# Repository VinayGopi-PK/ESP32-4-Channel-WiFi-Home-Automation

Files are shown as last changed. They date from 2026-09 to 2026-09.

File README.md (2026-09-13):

# ESP32 4-Channel Wi-Fi Home Automation

An **ESP32-based 4-channel Wi-Fi Home Automation Controller** designed for wireless control of electrical loads using four relay outputs.

The project includes a custom hardware design developed in **KiCad**, covering the schematic, PCB layout, power supply section, ESP32 programming interface, relay control circuitry, indicators, and PCB 3D visualization.

---

## Project Overview

This project is a compact **4-channel Wi-Fi Home Automation Controller** based on an ESP32 module.

The controller is designed to provide four independent relay-controlled outputs that can be operated through the ESP32's Wi-Fi connectivity.

The PCB integrates the ESP32 controller, isolated AC-to-DC power supply, 3.3 V regulation, USB programming interface, relay control circuitry, status indicators, and four relay outputs into a single custom PCB.

### Basic System Architecture

```text
                    AC INPUT
                       │
                       ▼
              ┌─────────────────┐
              │  Isolated AC-DC │
              │   Power Supply  │
              └────────┬────────┘
                       │
                       ▼
                  +5V DC Rail
                       │
             ┌─────────┴─────────┐
             │                   │
             ▼                   ▼
       3.3V Regulator       Relay Section
             │                   │
             ▼                   ▼
          ESP32 MCU        4 × Relays
             │                   │
             └─────────┬─────────┘
                       │
                 Wi-Fi Control
                       │
                       ▼
                 Home Appliances
```

---

## Main Features

* ESP32-based Wi-Fi controller
* 4 independent relay channels
* Custom PCB designed using KiCad
* Isolated AC-to-DC power supply section
* 5 V system power rail
* 3.3 V regulated supply for ESP32
* USB interface for programming and communication
* CP2102 USB-to-UART interface
* Auto-programming support
* BOOT and RESET controls
* Individual relay control circuitry
* Status indication LEDs
* Custom PCB layout
* Front and back copper routing
* 3D PCB visualization
* Manufacturing-oriented PCB design

---

## Hardware

| Component | Function |
| --- | --- |
| ESP32 | Main microcontroller and Wi-Fi connectivity |
| HLK-PM01 | Isolated AC-to-DC power supply |
| AMS1117-3.3 | 3.3 V voltage regulation |
| CP2102 | USB-to-UART programming interface |
| SANYOU SRD Relays | Switching of four output channels |
| SS14 | Power protection / rectification section |
| BOOT Button | ESP32 boot-mode control |
| RESET Button | ESP32 reset control |
| Status LEDs | Power / system / channel indication |
| Micro USB | Power/programming interface |

---

## 4-Channel Relay Control

The PCB provides **four independent relay channels** for controlling external electrical loads.

```text
                    ESP32
                      │
          ┌───────────┼───────────┐───────────┐   
          │           │           │           │
          ▼           ▼           ▼           ▼
       Channel 1   Channel 2   Channel 3   Channel 4
          │           │           │           │
          ▼           ▼           ▼           ▼
       Relay 1     Relay 2     Relay 3     Relay 4
          │           │           │           │
          ▼           ▼           ▼           ▼
       LOAD 1      LOAD 2      LOAD 3      LOAD 4
```

Each relay channel is controlled independently by the ESP32.

---

## Power Supply

The PCB incorporates an **isolated AC-to-DC power supply section** to provide the required DC power for the controller.

The power architecture includes:

* AC input
* Isolated AC-to-DC conversion
* +5 V system rail
* 3.3 V regulation
* ESP32 power supply
* Relay power supply
* Power protection components

The design separates the low-voltage control circuitry from the incoming AC section through the isolated power supply.

---

## USB Programming Interface

The PCB includes a **CP2102 USB-to-UART interface** for programming and serial communication with the ESP32.

The programming section includes:

* Micro USB connector
* CP2102 USB-to-UART bridge
* ESP32 UART connection
* Auto-programming circuitry
* BOOT control
* RESET control

This allows the ESP32 firmware to be programmed without requiring a separate external USB-to-UART module.

---

## Indicators and Controls

The design includes dedicated user-interface components for operating and monitoring the controller.

### Controls

* BOOT button
* RESET button

### Indicators

* Power/system status indication
* Relay/channel status indication

The PCB uses compact SMD LEDs for status indication while retaining convenient physical controls for programming and reset operations.

---

## PCB Design

The complete PCB was designed using **KiCad**.

The design includes:

* Complete electrical schematic
* Component selection and footprint assignment
* PCB component placement
* Signal routing
* Power routing
* Ground plane
* Relay section
* AC input section
* USB programming section
* ESP32 section
* Front and back PCB layout
* 3D PCB visualization
* Manufacturing files

---

## PCB Design Preview

### Schematic

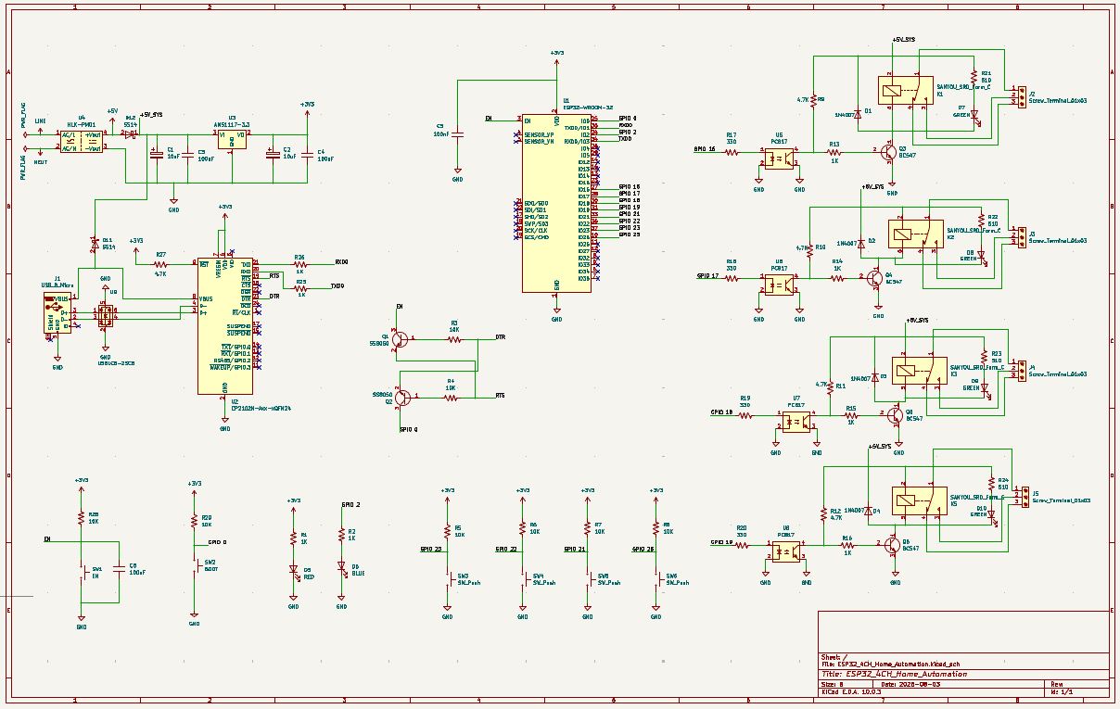
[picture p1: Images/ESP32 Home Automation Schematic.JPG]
ESP32 Home Automation Schematic


### PCB Front Layout

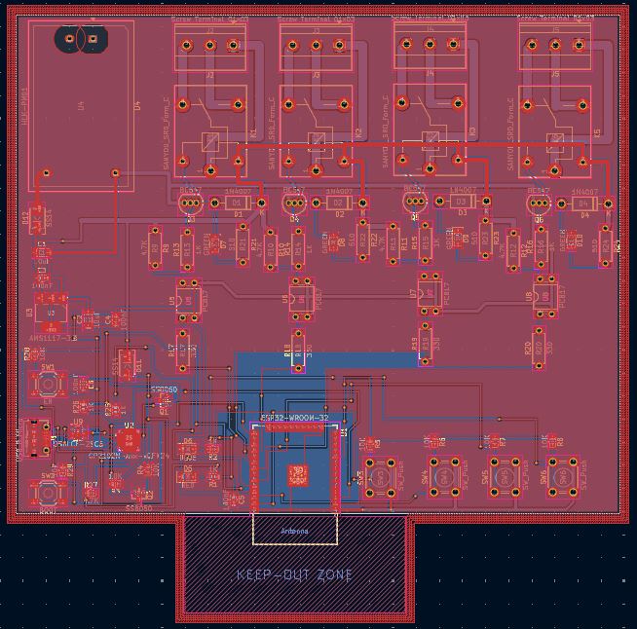
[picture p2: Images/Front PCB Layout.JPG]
ESP32 4-Channel Home Automation PCB Front Layout


### PCB Back Layout

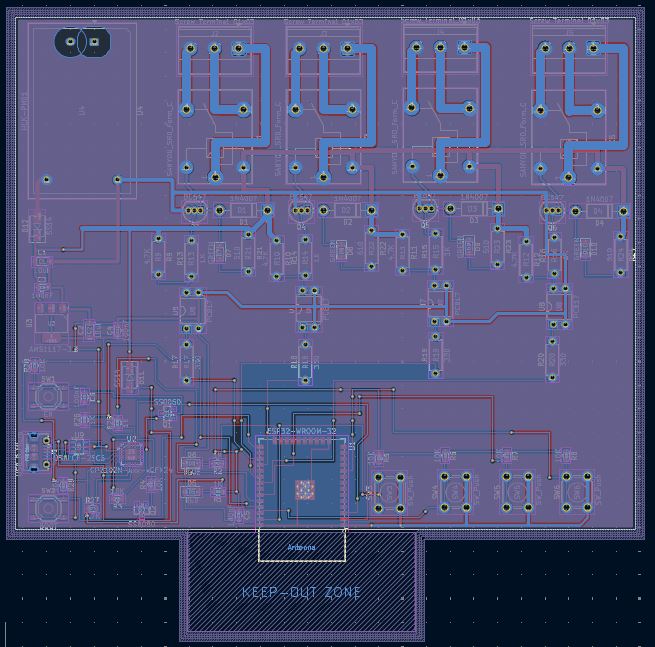
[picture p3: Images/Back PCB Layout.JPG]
ESP32 4-Channel Home Automation PCB Back Layout


### 3D View

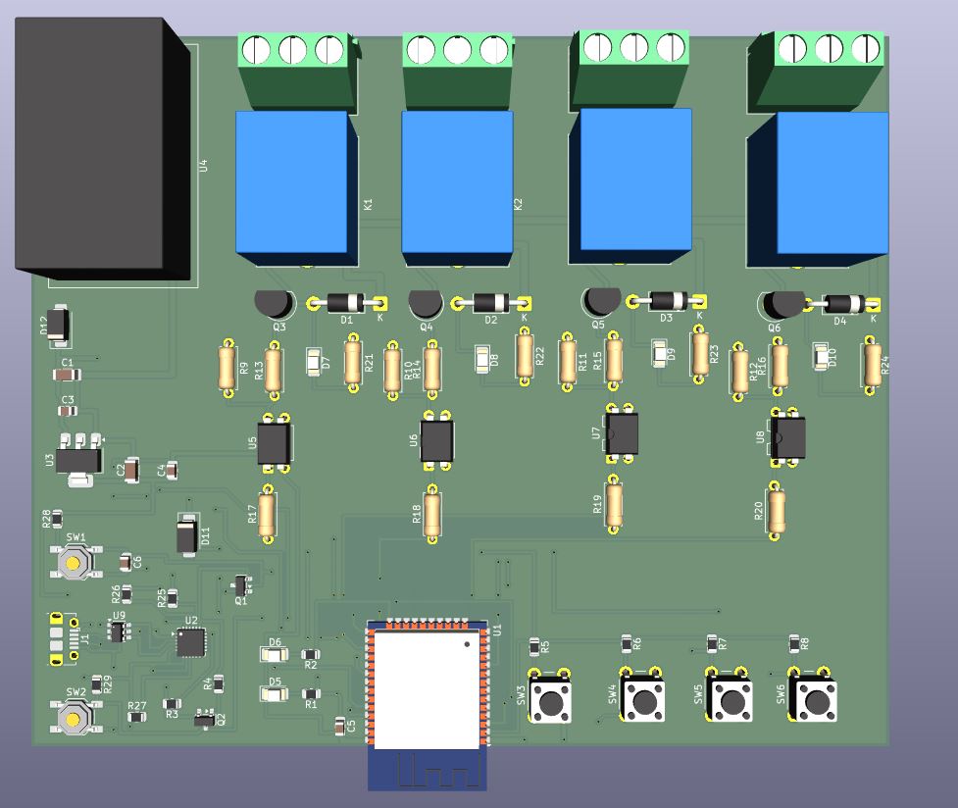
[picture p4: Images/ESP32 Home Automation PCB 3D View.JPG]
ESP32 4-Channel Home Automation PCB 3D View


---

## Design Considerations

The PCB design considers the separation between the **AC mains section and low-voltage electronics**.

Important design considerations include:

* Isolation between AC input and low-voltage circuitry
* Dedicated power distribution
* Ground-plane implementation
* Appropriate PCB clearances
* Relay switching section
* ESP32 signal routing
* USB programming interface
* Component placement
* Manufacturing requirements

> **Safety note:** This project involves mains-voltage circuitry. The PCB should only be assembled, tested, and operated by appropriately qualified personnel using suitable electrical safety practices and enclosure/isolation measures.

---

## Design Tools

* **KiCad** — Schematic and PCB design
* **ESP32** — Embedded Wi-Fi controller
* **CP2102** — USB-to-UART interface

---

## Technical Highlights

**Microcontroller:** ESP32
**Wireless Communication:** Wi-Fi
**Relay Channels:** 4
**AC-DC Power Supply:** HLK-PM01
**Logic Supply:** 3.3 V
**USB-UART:** CP2102
**Relay:** SANYOU SRD Series
**PCB Design Tool:** KiCad
**PCB Type:** Custom PCB

---

## Repository Contents

The repository contains the project design files, PCB manufacturing files, documentation, and project images.

### KiCad Project

Contains:

* KiCad schematic
* KiCad PCB layout
* KiCad project files
* Component and footprint configuration files

### Documentation

Contains project-related documentation and component information.

### Gerber Files

Contains the generated PCB manufacturing files.

### Images

Contains:

* Schematic
* PCB front layout
* PCB back layout
* PCB 3D view

---

## Project Objective

The objective of this project was to design a **compact 4-channel ESP32-based Wi-Fi Home Automation Controller** integrating wireless control, relay switching, isolated power conversion, USB programming, and custom PCB design into a single hardware platform.

The project demonstrates skills in:

* Embedded system hardware design
* ESP32-based systems
* Wi-Fi-enabled control systems
* Power supply design
* Relay control
* USB-to-UART programming
* Schematic design
* PCB layout
* Component selection
* PCB manufacturing file generation

---

## Project Type

**ESP32 Embedded System | Wi-Fi Home Automation | Relay Controller | PCB Design**

**Design Software:** KiCad
**Controller:** ESP32

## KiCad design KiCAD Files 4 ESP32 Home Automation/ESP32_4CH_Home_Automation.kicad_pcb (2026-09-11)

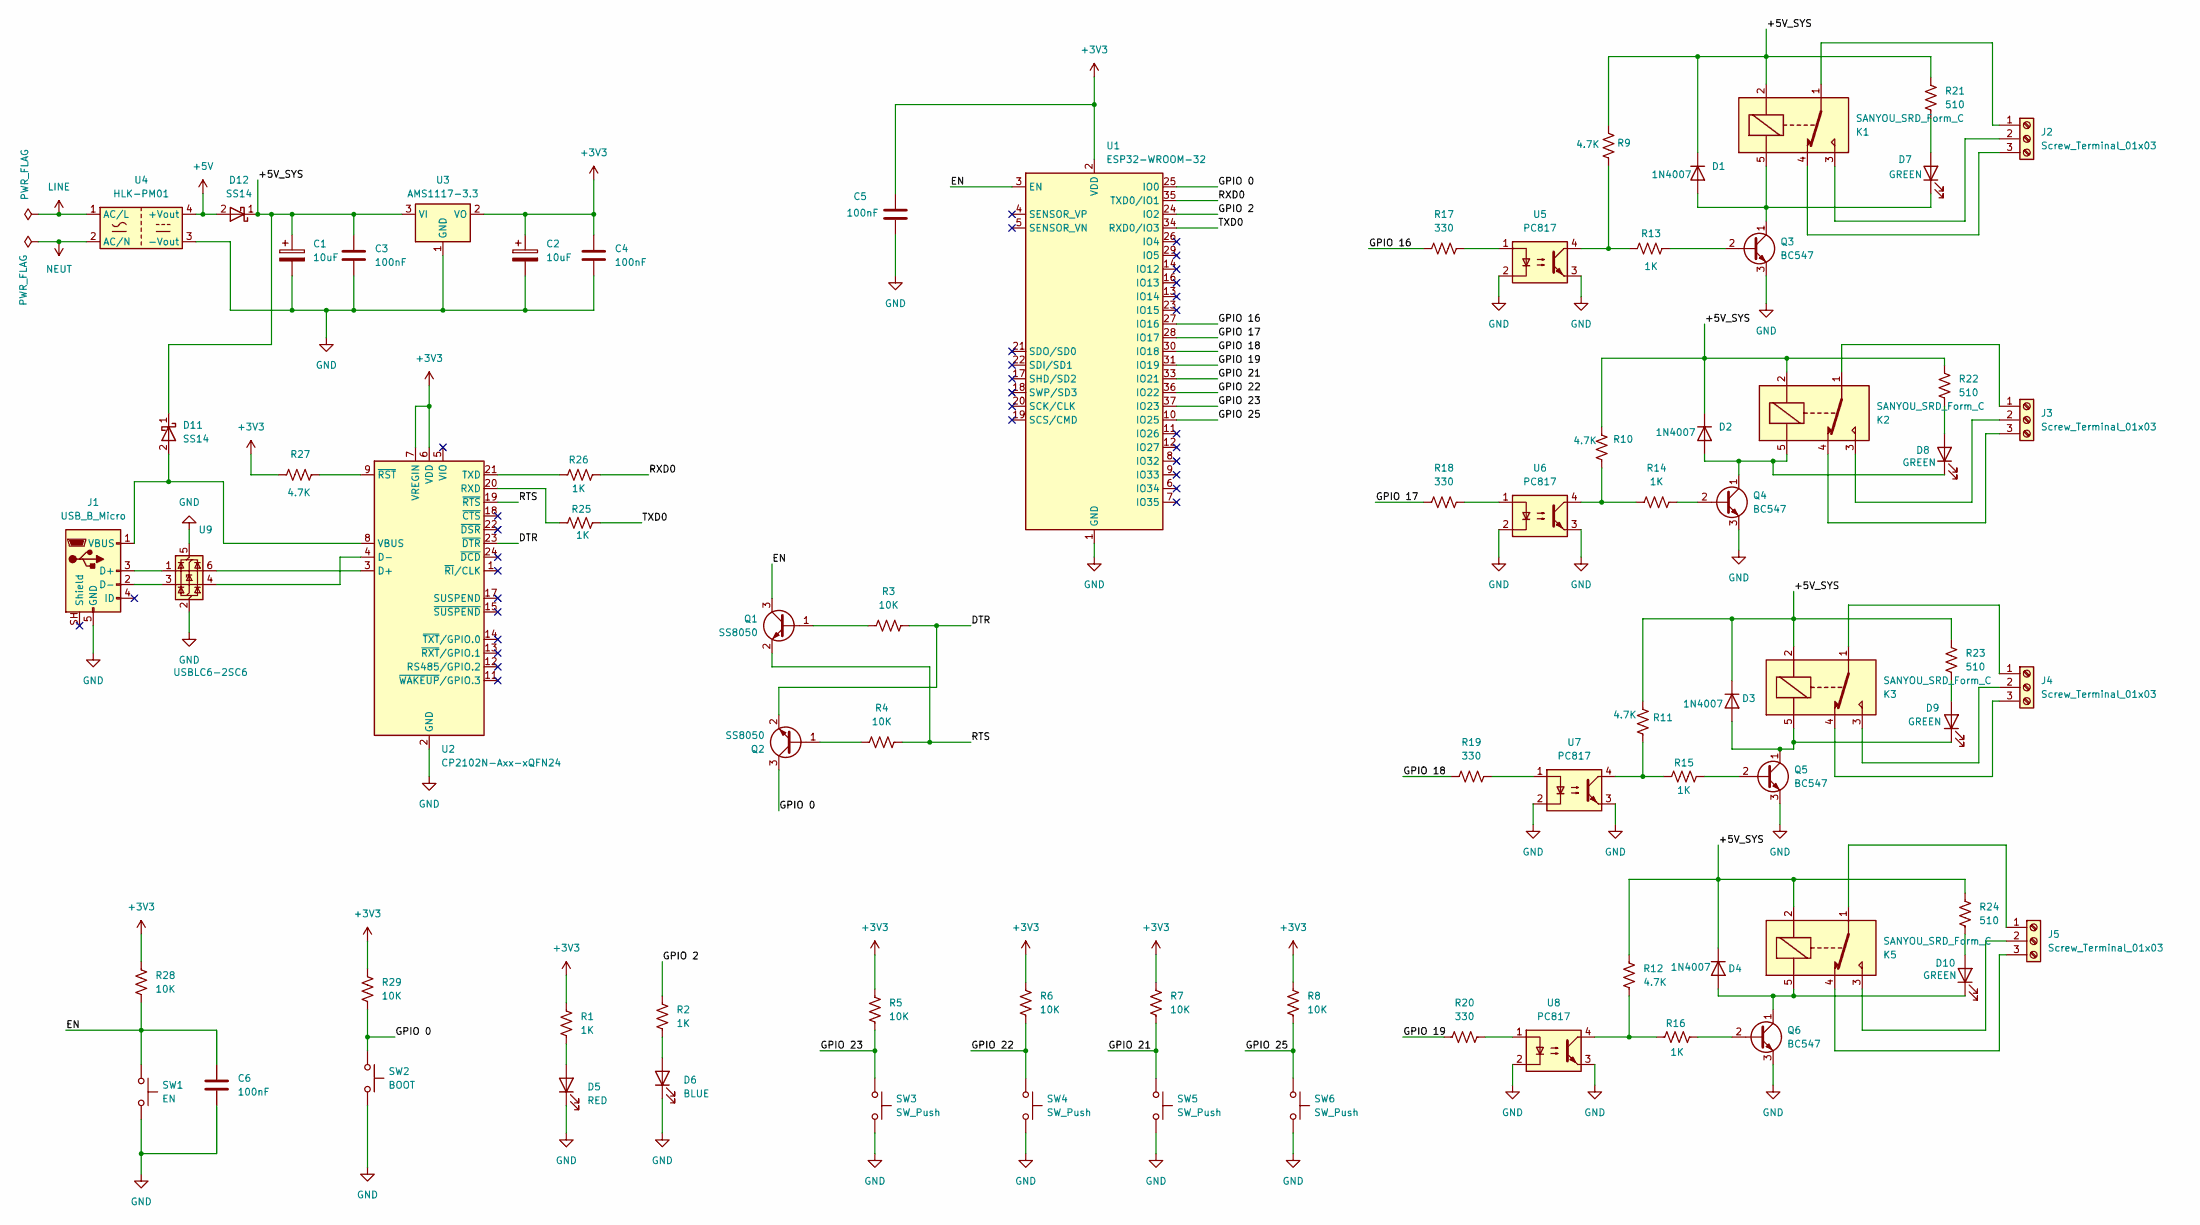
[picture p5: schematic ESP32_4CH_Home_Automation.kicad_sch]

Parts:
C1, C2: 10uF; C_1206_3216Metric
C3, C4, C5, C6: 100nF; C_0805_2012Metric
D1, D2, D3, D4: 1N4007; D_DO-41_SOD81_P10.16mm_Horizontal
D5: RED; LED_1206_3216Metric
D6: BLUE; LED_1206_3216Metric
D7, D8, D9, D10: GREEN; LED_1206_3216Metric
D11, D12: SS14; D_SMA
J1: USB_B_Micro; USB_Micro-B_Molex-105017-0001
J2, J3, J4, J5: Screw_Terminal_01x03; TerminalBlock_Phoenix_MKDS-1,5-3-5.08_1x03_P5.08mm_Horizont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
K1, K2, K3, K5: SANYOU_SRD_Form_C; Relay_SPDT_SANYOU_SRD_Series_Form_C
Q1, Q2: SS8050; SOT-23
Q3, Q4, Q5, Q6: BC547; TO-92_Inline
R1, R2, R25, R26: 1K; R_0805_2012Metric
R3, R4, R5, R6, R7, R8, R28, R29: 10K; R_0805_2012Metric
R9, R10, R11, R12: 4.7K; R_Axial_DIN0207_L6.3mm_D2.5mm_P7.62mm_Horizontal
R13, R14, R15, R16: 1K; R_Axial_DIN0207_L6.3mm_D2.5mm_P7.62mm_Horizontal
R17, R18, R19, R20: 330; R_Axial_DIN0207_L6.3mm_D2.5mm_P7.62mm_Horizontal
R21, R22, R23, R24: 510; R_Axial_DIN0207_L6.3mm_D2.5mm_P7.62mm_Horizontal
R27: 4.7K; R_0805_2012Metric
SW1: EN; SW_SPST_TL3342
SW2: BOOT; SW_SPST_TL3342
SW3, SW4, SW5, SW6: SW_Push; SW_PUSH_6mm
U1: ESP32-WROOM-32
U2: CP2102N-Axx-xQFN24; QFN-24-1EP_4x4mm_P0.5mm_EP2.6x2.6mm
U3: AMS1117-3.3; SOT-223-3_TabPin2
U4: HLK-PM01; Converter_ACDC_Hi-Link_HLK-PMxx
U5, U6, U7, U8: PC817; DIP-4_W7.62mm
U9: USBLC6-2SC6; SOT-23-6

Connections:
+3V3: C2.1, C4.1, C5.1, R1.1, R5.1, R6.1, R7.1, R8.1, R27.1, R28.2, R29.1, U1.2 (VDD), U2.6 (VDD), U2.7 (VREGIN), U3.2 (VO)
+5V: D12.2 (A), U4.4 (+Vout)
/+5V_SYS: C1.1, C3.1, D1.1 (K), D2.1 (K), D3.1 (K), D4.1 (K), D11.1 (K), D12.1 (K), K1.2, K2.2, K3.2, K5.2, R9.1, R10.1, R11.1, R12.1, R21.1, R22.1, R23.1, R24.1, U3.3 (VI)
/DTR: Q2.2 (E), R3.2, U2.23 (~DTR)
/EN: C6.1, Q1.3 (C), R28.1, SW1.1, U1.3 (EN)
/GPIO 0: Q2.3 (C), R29.2, SW2.1, U1.25 (IO0)
/GPIO 2: R2.1, U1.24 (IO2)
/GPIO 16: R17.1, U1.27 (IO16)
/GPIO 17: R18.1, U1.28 (IO17)
/GPIO 18: R19.1, U1.30 (IO18)
/GPIO 19: R20.1, U1.31 (IO19)
/GPIO 21: R7.2, SW5.1, U1.33 (IO21)
/GPIO 22: R6.2, SW4.1, U1.36 (IO22)
/GPIO 23: R5.2, SW3.1, U1.37 (IO23)
/GPIO 25: R8.2, SW6.1, U1.10 (IO25)
/RTS: Q1.2 (E), R4.2, U2.19 (~RTS)
/RXD0: R26.2, U1.35 (TXD0/IO1)
/TXD0: R25.2, U1.34 (RXD0/IO3)
GND: C1.2, C2.2, C3.2, C4.2, C5.2, C6.2, D5.1 (K), D6.1 (K), J1.5 (GND), Q3.3 (E), Q4.3 (E), Q5.3 (E), Q6.3 (E), SW1.2, SW2.2, SW3.2, SW4.2, SW5.2, SW6.2, U1.1 (GND), U1.15 (GND), U1.38 (GND), U1.39 (GND), U2.2 (GND), U2.25 (GND), U3.1 (GND), U4.3 (-Vout), U5.2, U5.3, U6.2, U6.3, U7.2, U7.3, U8.2, U8.3, U9.2 (GND), U9.5 (VBUS)
LINE: U4.1 (AC/L)
NEUT: U4.2 (AC/N)
unnamed: D1.2 (A), D7.1 (K), K1.5, Q3.1 (C)
unnamed: D2.2 (A), D8.1 (K), K2.5, Q4.1 (C)
unnamed: D3.2 (A), D9.1 (K), K3.5, Q5.1 (C)
unnamed: D5.2 (A), R1.2
unnamed: D6.2 (A), R2.2
unnamed: D7.2 (A), R21.2
unnamed: D8.2 (A), R22.2
unnamed: D9.2 (A), R23.2
unnamed: D10.2 (A), R24.2
unnamed: D4.2 (A), D10.1 (K), K5.5, Q6.1 (C)
unnamed: D11.2 (A), J1.1 (VBUS), U2.8 (VBUS)
unnamed: J1.3 (D+), U9.1 (I/O1)
unnamed: J1.2 (D-), U9.3 (I/O2)
unnamed: J2.1, K1.1
unnamed: J2.2, K1.3
unnamed: J2.3, K1.4
unnamed: J3.1, K2.1
unnamed: J3.2, K2.3
unnamed: J3.3, K2.4
unnamed: J4.1, K3.1
unnamed: J4.2, K3.3
unnamed: J4.3, K3.4
unnamed: J5.1, K5.1
unnamed: J5.2, K5.3
unnamed: J5.3, K5.4
unnamed: Q1.1 (B), R3.1
unnamed: Q2.1 (B), R4.1
unnamed: Q3.2 (B), R13.2
unnamed: Q4.2 (B), R14.2
unnamed: Q5.2 (B), R15.2
unnamed: Q6.2 (B), R16.2
unnamed: R10.2, R14.1, U6.4
unnamed: R11.2, R15.1, U7.4
unnamed: R12.2, R16.1, U8.4
unnamed: R9.2, R13.1, U5.4
unnamed: R17.2, U5.1
unnamed: R18.2, U6.1
unnamed: R19.2, U7.1
unnamed: R20.2, U8.1
unnamed: U2.3 (D+), U9.6 (I/O1)
unnamed: U2.4 (D-), U9.4 (I/O2)
unnamed: R25.1, U2.20 (RXD)
unnamed: R26.1, U2.21 (TXD)
unnamed: R27.2, U2.9 (~RST)

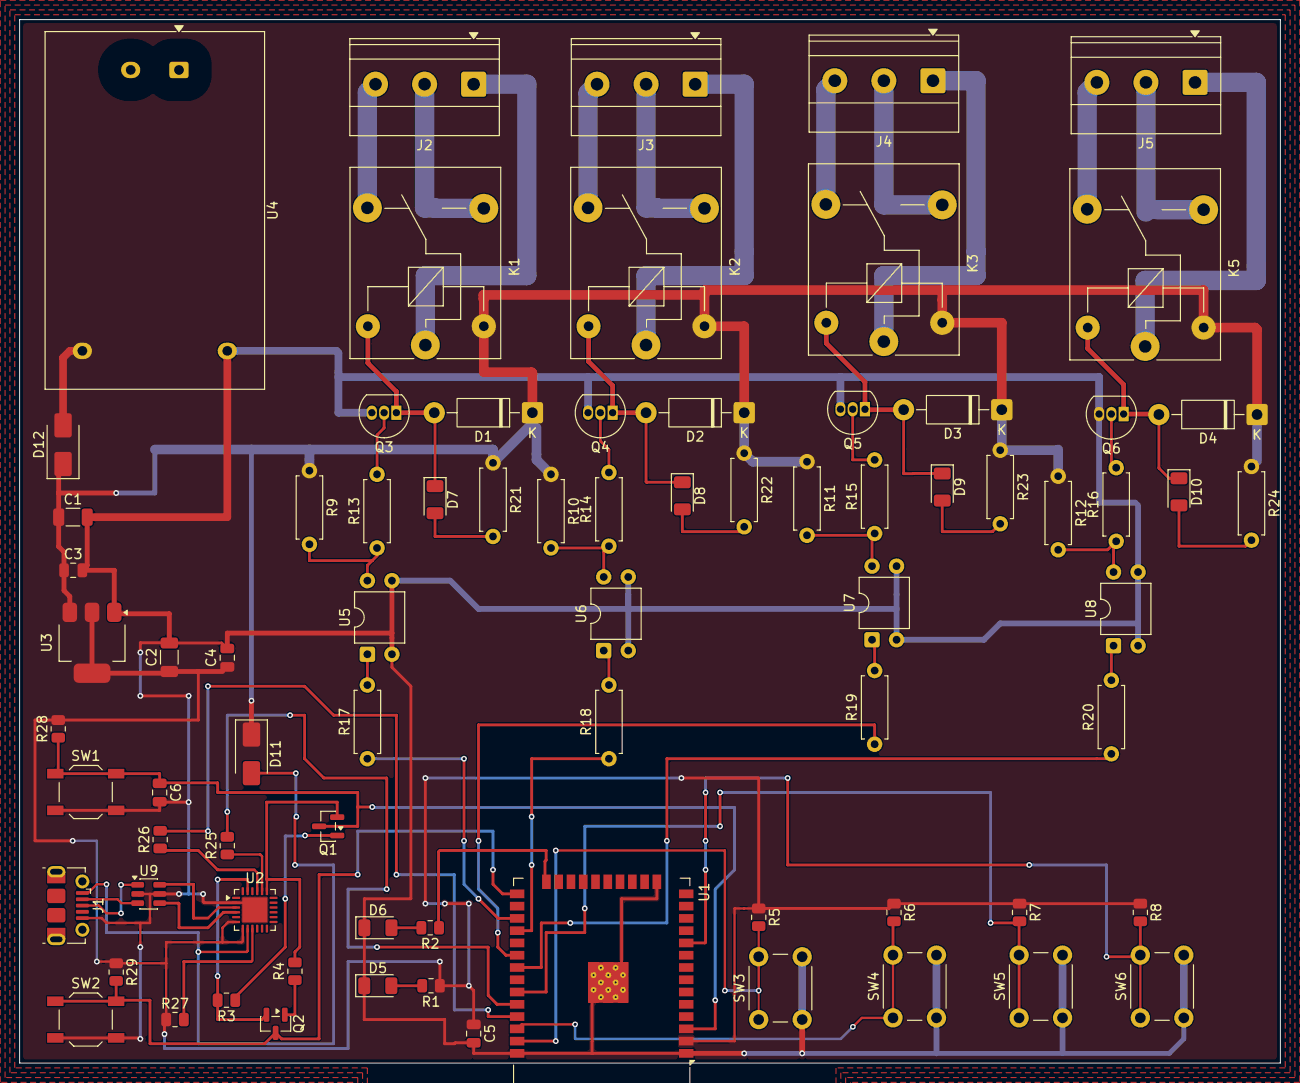
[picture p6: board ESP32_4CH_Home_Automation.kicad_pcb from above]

Board: 2 copper layers, 130.5 x 108.0 mm, 77 parts (0 on the bottom side), 63 nets.

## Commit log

2026-09-11 Revise README for ESP32 Home Automation project
    Updated the README to provide a detailed project overview, features, hardware components, and design considerations for the ESP32 4-Channel Wi-Fi Home Automation Controller.
2026-09-11 Fix schematic image filename in README
    Updated image reference for the schematic in the README.
2026-09-13 Fix image links in PCB design preview section
    Updated image links in README for PCB design section.
2026-09-13 Update diagram in README for ESP32 channels
